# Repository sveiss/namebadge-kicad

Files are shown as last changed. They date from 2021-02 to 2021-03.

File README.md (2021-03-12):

namebadge-kicad
===============

This repo contains the Kicad data files for an animated desk toy/namebadge with the letter K, built using WS2812 LEDs (Adafruit "NeoPixels") and a Raspberry Pi Pico.

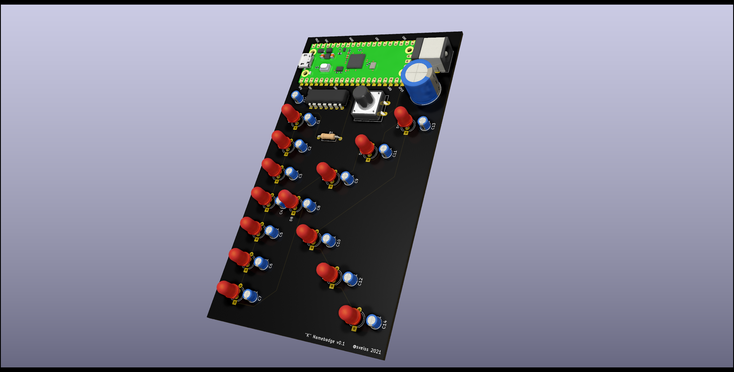
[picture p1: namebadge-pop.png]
PCB Render


*Note*: This is my first electronics project in a very long while -- don't use this project as an example of how to do things right!

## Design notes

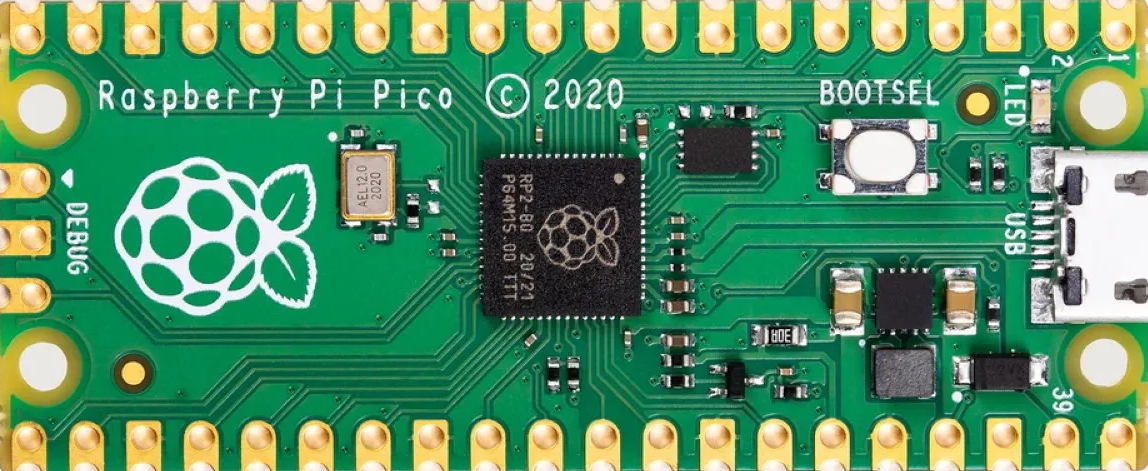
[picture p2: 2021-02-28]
raspberry-pi-pico-r3-1.snapshot.1/Raspberry Pi Pico-R3, Top View.PNG

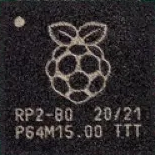
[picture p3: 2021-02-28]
raspberry-pi-pico-r3-1.snapshot.1/RP2040 Microcontroller, Raspberry Pi Pico-R3, Top View.PNG

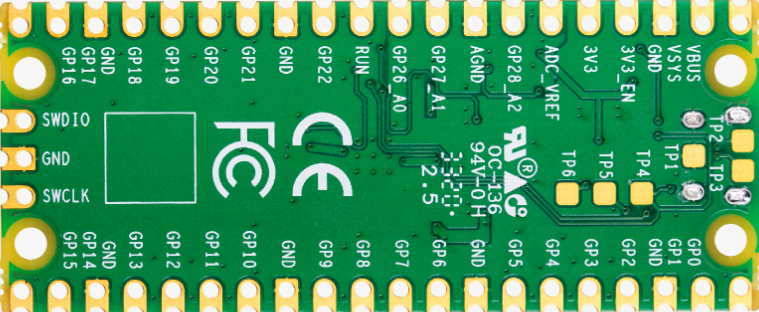
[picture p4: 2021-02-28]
raspberry-pi-pico-r3-1.snapshot.1/Raspberry Pi Pico-R3, Bottom View.PNG

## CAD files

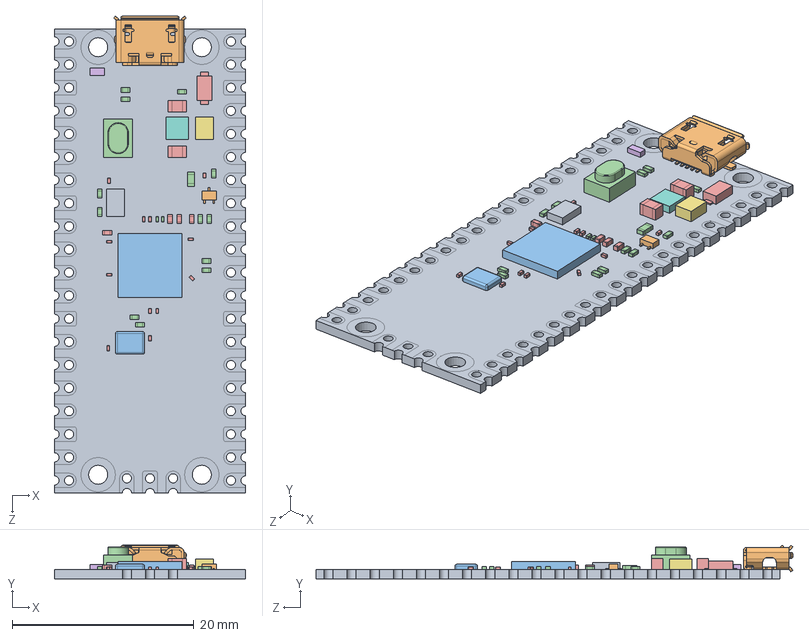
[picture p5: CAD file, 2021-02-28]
raspberry-pi-pico-r3-1.snapshot.1/Raspberry Pi Pico-R3.SLDASM
21.0 x 3.69 x 52.4 mm
PCB, Raspberry Pi Pico-R3
MicroUSB Port, Raspberry Pi Pico-R3
RP2040 Microcontroller, Raspberry Pi Pico-R3
SW1, Tact Switch, Raspberry Pi Pico-R3
D1, Diode, Schottky, Raspberry Pi Pico-R3
D2, QSME-C194, LED, Raspberry Pi Pico-R3
L1, Inductor, Raspberry Pi Pico-R3
U2, RT6150B-33GQW, Buck Boost Converter, Raspberry Pi Pico-R3
U3, W25Q16JVUXIQ, Serial NOR Flash 16 Mbit, Raspberry Pi Pico-R3
Q1, MOSFET, DMG1012T, Raspberry Pi Pico-R3
X1, X12M000000S096, 12 Mhz Crystal Resonator, Raspberry Pi Pico-R3
SMD Resistor, Configurable, Raspberry Pi Pico-R3 x 15
SMD Capacitor, Configurable, Raspberry Pi Pico-R3 x 18

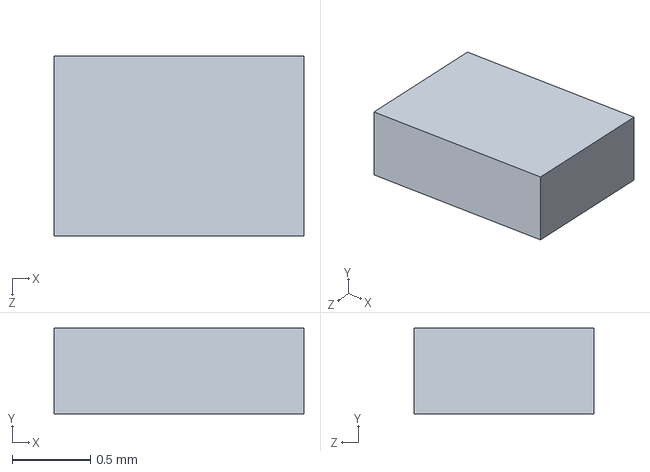
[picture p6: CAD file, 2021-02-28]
raspberry-pi-pico-r3-1.snapshot.1/D2, QSME-C194, LED, Raspberry Pi Pico-R3.SLDPRT
1.60 x 0.55 x 1.15 mm

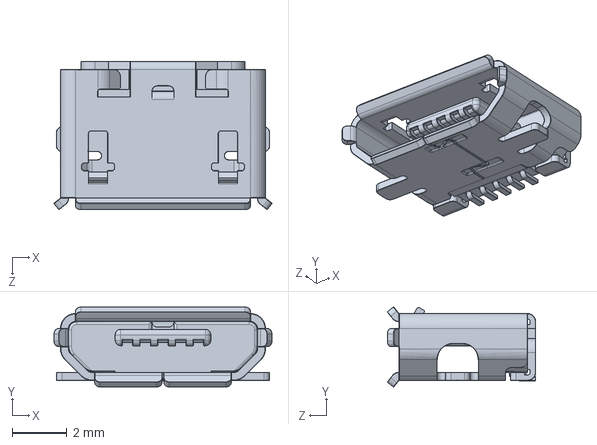
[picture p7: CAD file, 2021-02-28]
raspberry-pi-pico-r3-1.snapshot.1/MicroUSB Port, Raspberry Pi Pico-R3.SLDPRT
7.97 x 2.92 x 5.43 mm

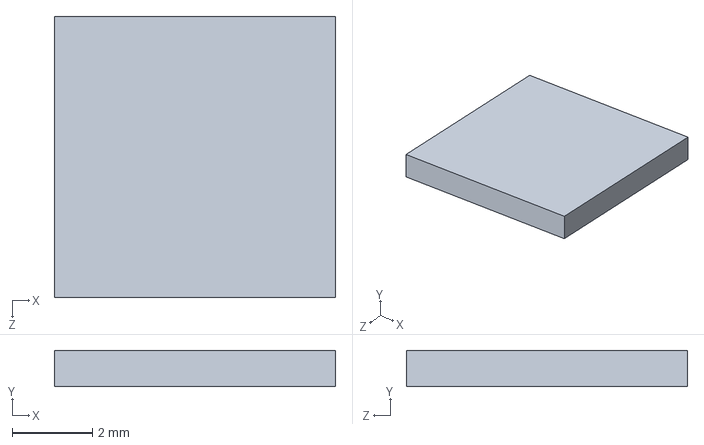
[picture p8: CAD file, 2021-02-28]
raspberry-pi-pico-r3-1.snapshot.1/RP2040 Microcontroller, Raspberry Pi Pico-R3.SLDPRT
7.00 x 0.9 x 7.00 mm

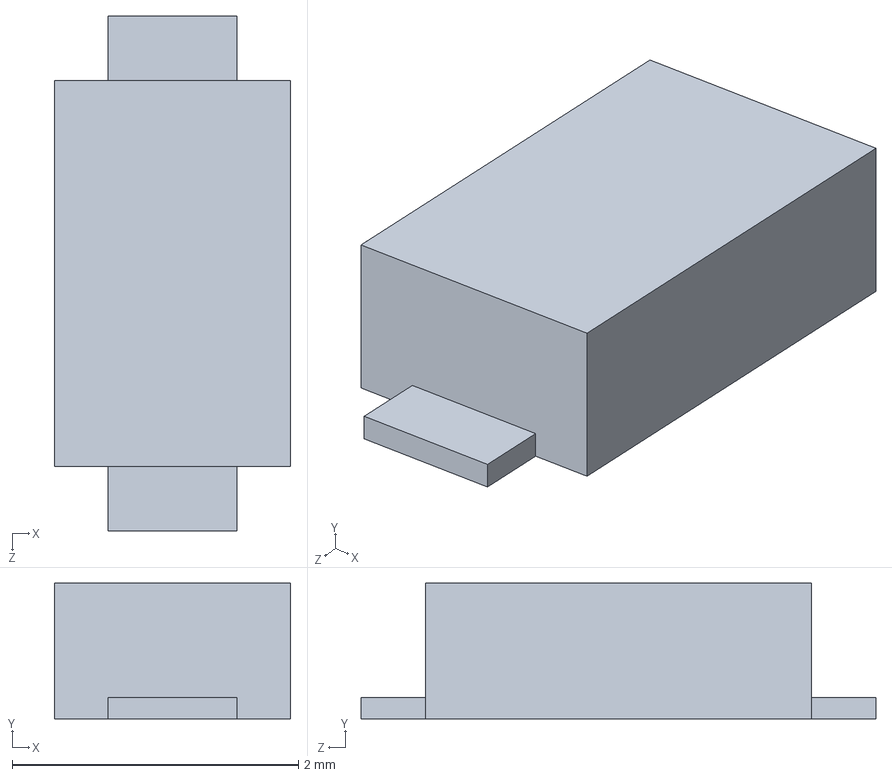
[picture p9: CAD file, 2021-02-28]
raspberry-pi-pico-r3-1.snapshot.1/D1, Diode, Schottky, Raspberry Pi Pico-R3.SLDPRT
1.65 x 0.95 x 3.60 mm

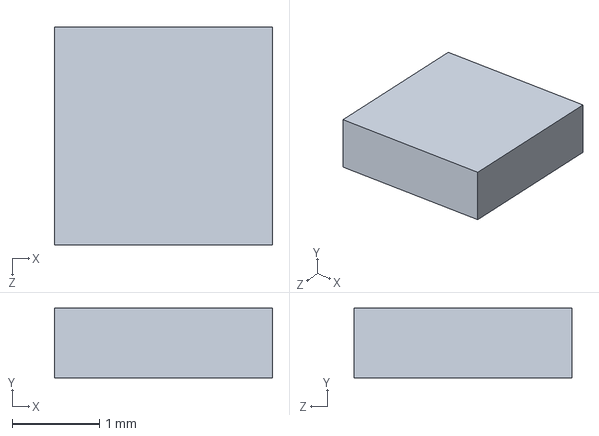
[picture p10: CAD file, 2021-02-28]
raspberry-pi-pico-r3-1.snapshot.1/U3, W25Q16JVUXIQ, Serial NOR Flash 16 Mbit, Raspberry Pi Pico-R3.SLDPRT
2.50 x 0.8 x 2.50 mm

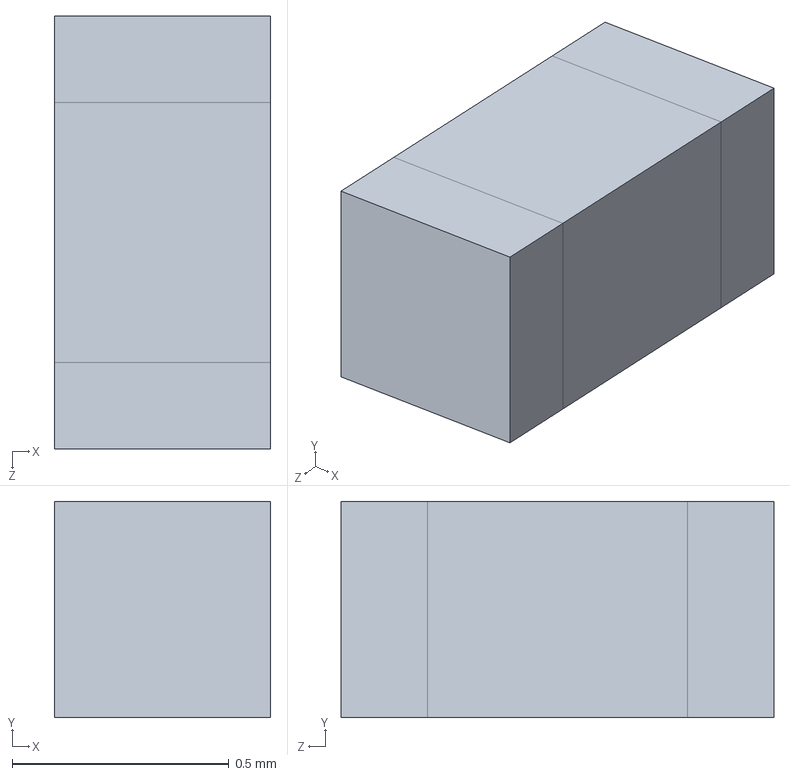
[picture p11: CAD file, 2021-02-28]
raspberry-pi-pico-r3-1.snapshot.1/SMD Capacitor, Configurable, Raspberry Pi Pico-R3.SLDPRT
0.5 x 0.5 x 1.00 mm

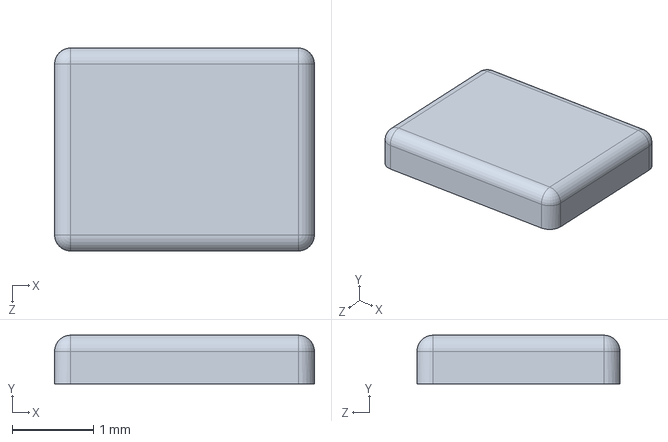
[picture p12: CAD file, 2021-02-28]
raspberry-pi-pico-r3-1.snapshot.1/X1, X12M000000S096, 12 Mhz Crystal Resonator, Raspberry Pi Pico-R3.SLDPRT
3.20 x 0.6 x 2.50 mm

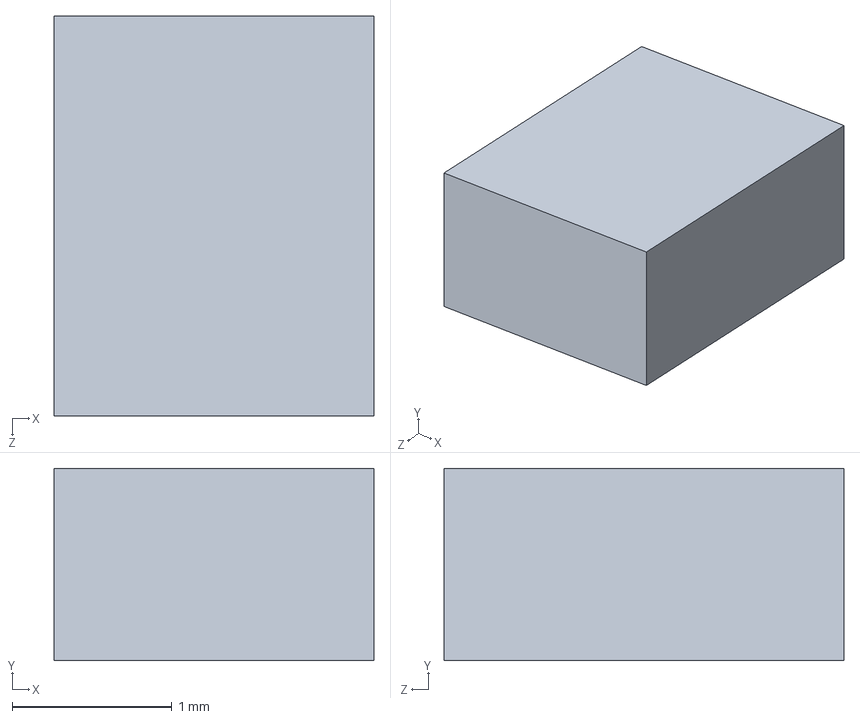
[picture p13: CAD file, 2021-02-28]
raspberry-pi-pico-r3-1.snapshot.1/L1, Inductor, Raspberry Pi Pico-R3.SLDPRT
2.00 x 1.20 x 2.50 mm

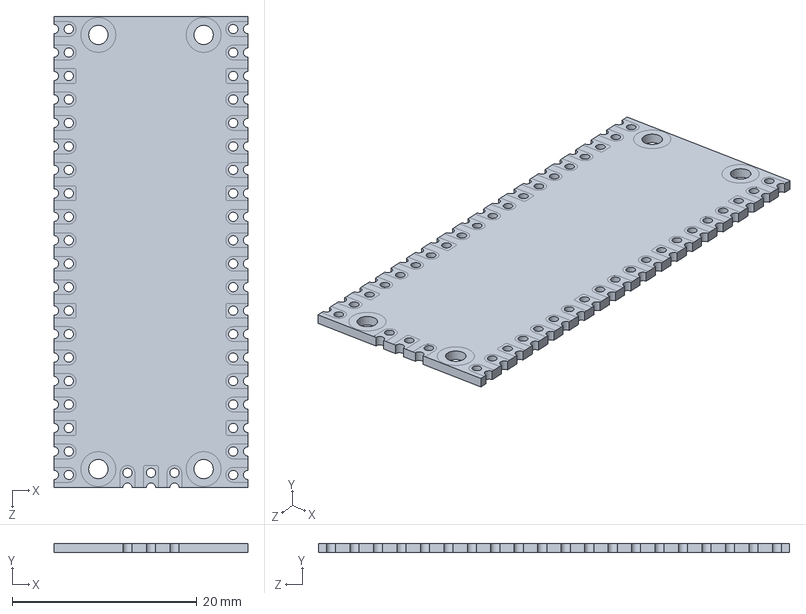
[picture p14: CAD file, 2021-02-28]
raspberry-pi-pico-r3-1.snapshot.1/PCB, Raspberry Pi Pico-R3.SLDPRT
21.0 x 1.00 x 51.0 mm

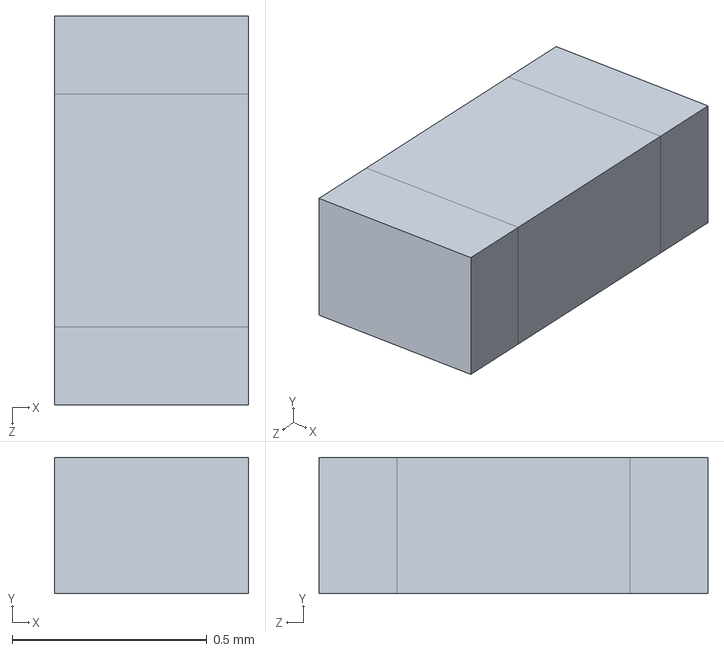
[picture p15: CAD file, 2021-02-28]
raspberry-pi-pico-r3-1.snapshot.1/SMD Resistor, Configurable, Raspberry Pi Pico-R3.SLDPRT
0.5 x 0.35 x 1.00 mm

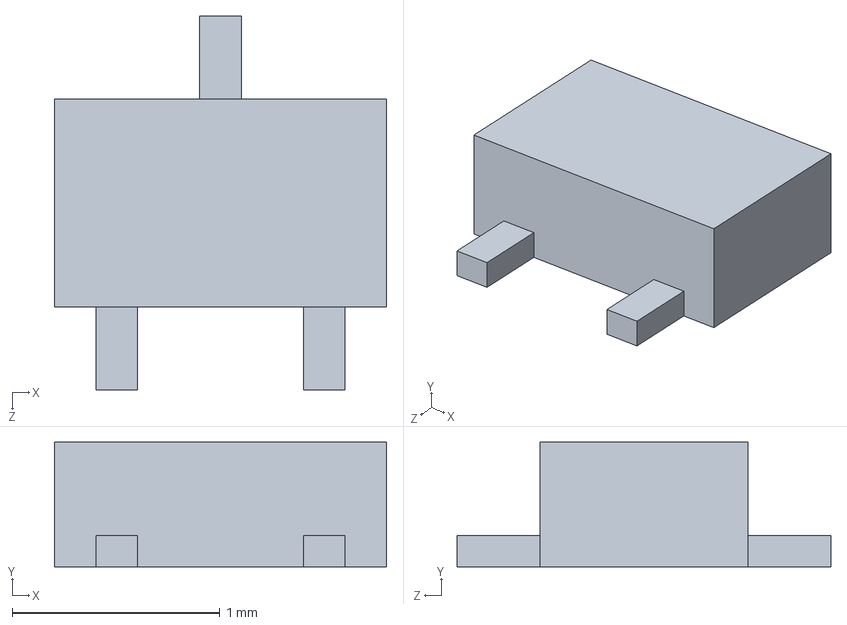
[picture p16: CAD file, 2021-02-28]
raspberry-pi-pico-r3-1.snapshot.1/Q1, MOSFET, DMG1012T, Raspberry Pi Pico-R3.SLDPRT
1.60 x 0.6 x 1.80 mm

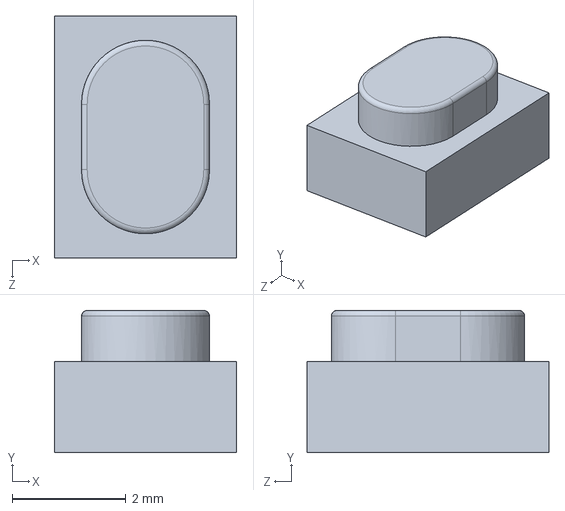
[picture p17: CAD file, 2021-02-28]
raspberry-pi-pico-r3-1.snapshot.1/SW1, Tact Switch, Raspberry Pi Pico-R3.SLDPRT
3.20 x 2.50 x 4.25 mm

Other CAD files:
raspberry-pi-pico-r3-1.snapshot.1/U2, RT6150B-33GQW, Buck Boost Converter, Raspberry Pi Pico-R3.SLDPRT
raspberry-pi-pico-r3-1.snapshot.1/Raspberry Pi Pico-R3.x_b

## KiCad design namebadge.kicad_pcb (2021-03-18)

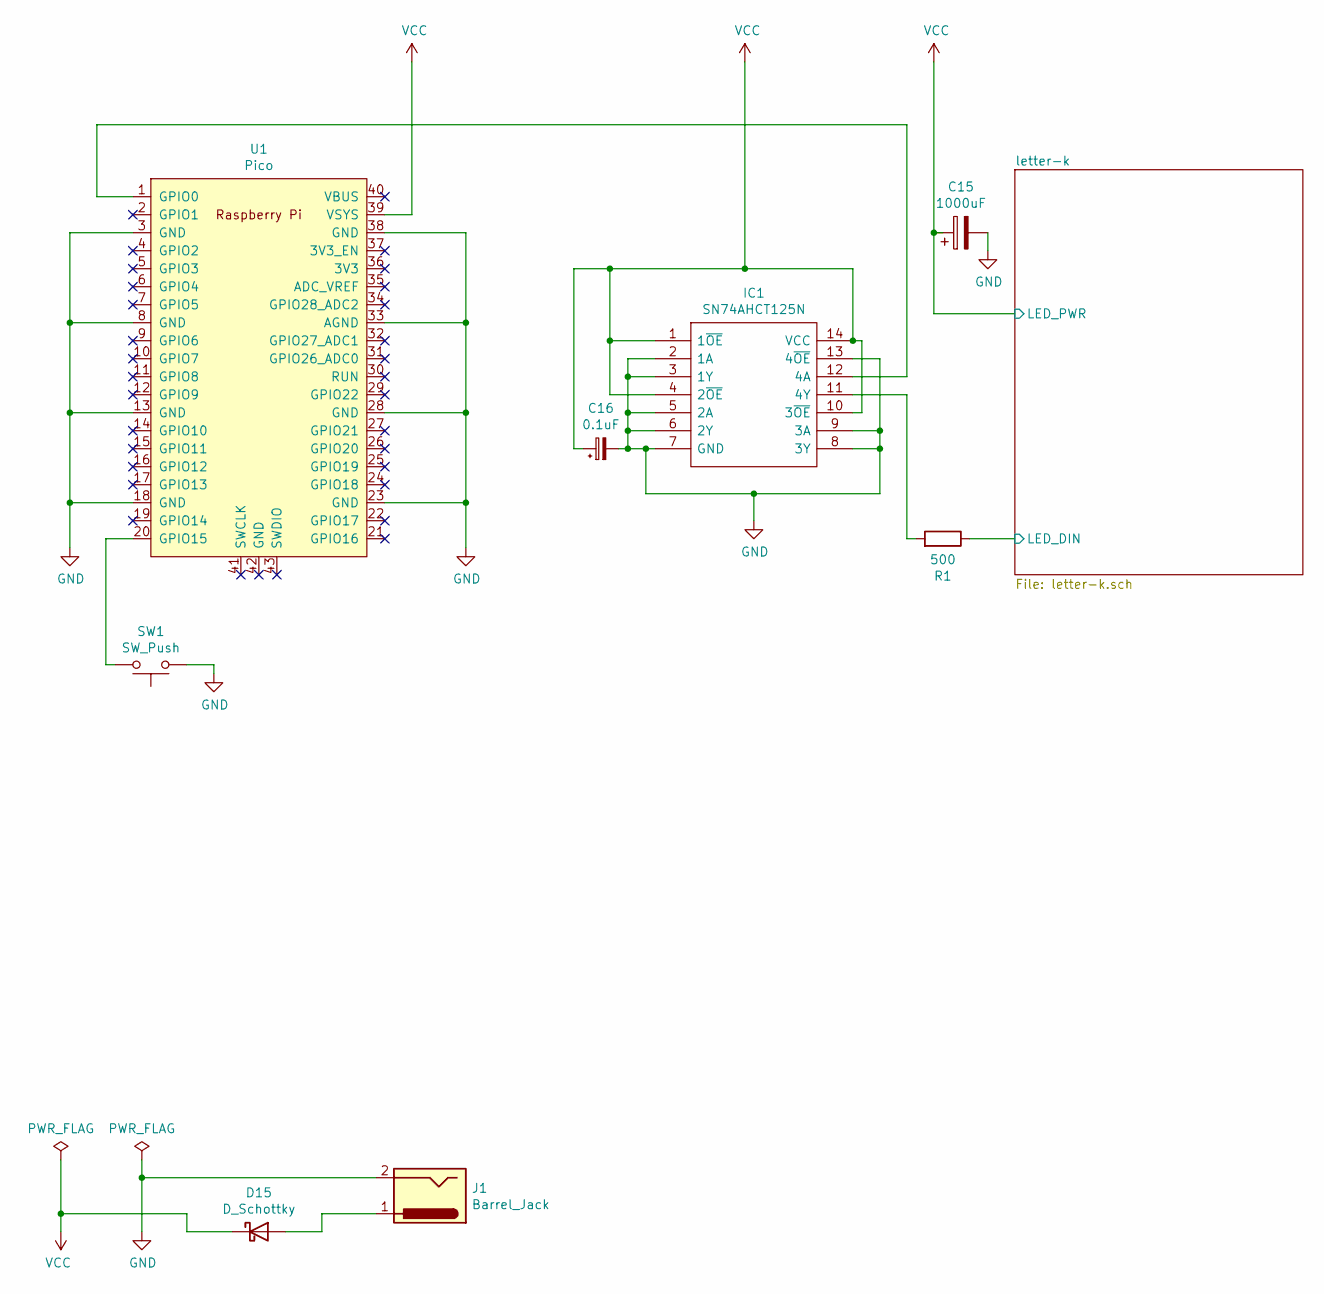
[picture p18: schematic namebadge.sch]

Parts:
C15: 1000uF; CP_Radial_D12.5mm_P5.00mm
C16: 0.1uF; C_Disc_D4.7mm_W2.5mm_P5.00mm
D15: D_Schottky; D_DO-41_SOD81_P10.16mm_Horizontal
IC1: SN74AHCT125N; DIP-14_W7.62mm; Manufacturer_Part_Number SN74AHCT125N; Mouser Part Number 595-SN74AHCT125N
J1: Barrel_Jack; BarrelJack_CUI_PJ-063AH_Horizontal
R1: 500; R_Axial_DIN0207_L6.3mm_D2.5mm_P10.16mm_Horizontal
SW1: SW_Push; SW_PUSH-12mm
U1: Pico; RPi_Pico_SMD_TH

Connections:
/letter-k/LED_DIN: R1.1; also elsewhere on the board
GND: C15.2, C16.2, IC1.2 (1A), IC1.3 (1Y), IC1.5 (2A), IC1.6 (2Y), IC1.7 (GND), IC1.8 (3Y), IC1.9 (3A), IC1.13 (4~OE), J1.2, SW1.1, U1.3 (GND), U1.8 (GND), U1.13 (GND), U1.18 (GND), U1.23 (GND), U1.28 (GND), U1.33 (AGND), U1.38 (GND); also elsewhere on the board
unnamed: D15.2 (A), J1.1
unnamed: IC1.11 (4Y), R1.2
unnamed: IC1.12 (4A), U1.1 (GPIO0)
unnamed: SW1.2, U1.20 (GPIO15)
VCC: C15.1, C16.1, D15.1 (K), IC1.1 (1~OE), IC1.4 (2~OE), IC1.10 (3~OE), IC1.14 (VCC), U1.39 (VSYS); also elsewhere on the board

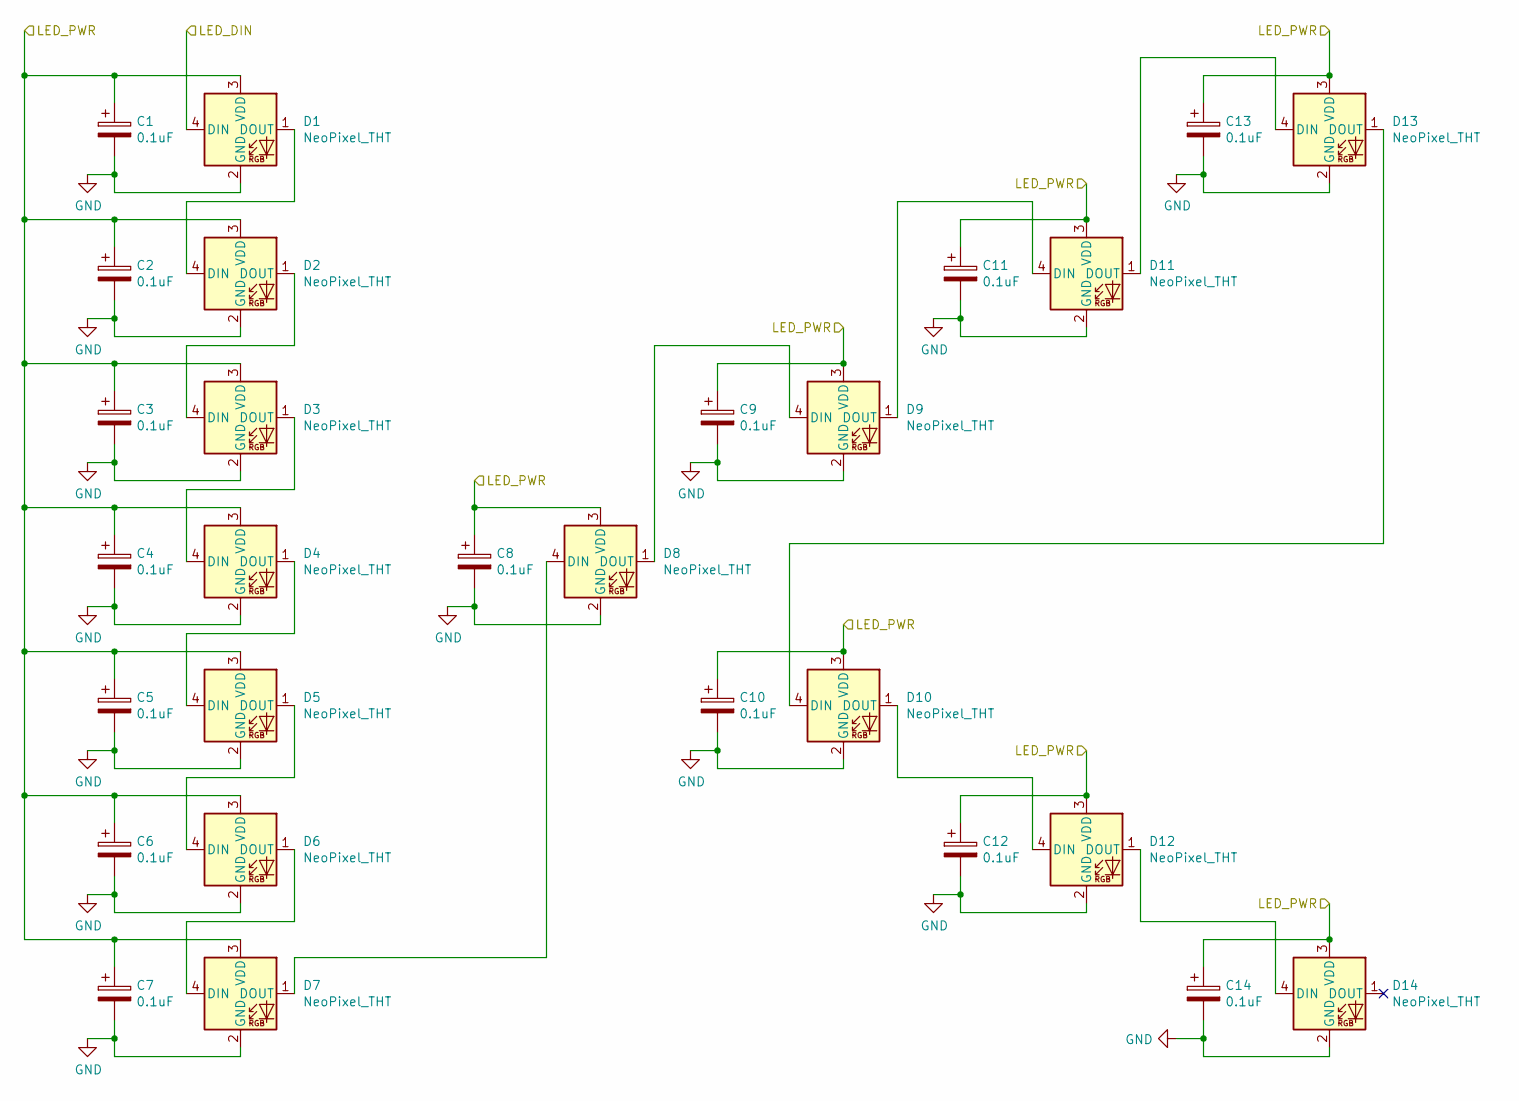
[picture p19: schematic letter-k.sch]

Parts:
C1, C2, C3, C4, C5, C6, C7, C8, C9, C10, C11, C12, C13, C14: 0.1uF; C_Disc_D4.7mm_W2.5mm_P5.00mm
D1, D2, D3, D4, D5, D6, D7, D8, D9, D10, D11, D12, D13, D14: NeoPixel_THT; LED_D5.0mm-4_RGB_Wide_Pins

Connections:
/letter-k/LED_DIN: D1.4 (DIN); also elsewhere on the board
GND: C1.2, C2.2, C3.2, C4.2, C5.2, C6.2, C7.2, C8.2, C9.2, C10.2, C11.2, C12.2, C13.2, C14.2, D1.2 (GND), D2.2 (GND), D3.2 (GND), D4.2 (GND), D5.2 (GND), D6.2 (GND), D7.2 (GND), D8.2 (GND), D9.2 (GND), D10.2 (GND), D11.2 (GND), D12.2 (GND), D13.2 (GND), D14.2 (GND); also elsewhere on the board
unnamed: D1.1 (DOUT), D2.4 (DIN)
unnamed: D2.1 (DOUT), D3.4 (DIN)
unnamed: D3.1 (DOUT), D4.4 (DIN)
unnamed: D4.1 (DOUT), D5.4 (DIN)
unnamed: D5.1 (DOUT), D6.4 (DIN)
unnamed: D6.1 (DOUT), D7.4 (DIN)
unnamed: D7.1 (DOUT), D8.4 (DIN)
unnamed: D8.1 (DOUT), D9.4 (DIN)
unnamed: D10.1 (DOUT), D12.4 (DIN)
unnamed: D10.4 (DIN), D13.1 (DOUT)
unnamed: D11.1 (DOUT), D13.4 (DIN)
unnamed: D9.1 (DOUT), D11.4 (DIN)
unnamed: D12.1 (DOUT), D14.4 (DIN)
VCC: C1.1, C2.1, C3.1, C4.1, C5.1, C6.1, C7.1, C8.1, C9.1, C10.1, C11.1, C12.1, C13.1, C14.1, D1.3 (VDD), D2.3 (VDD), D3.3 (VDD), D4.3 (VDD), D5.3 (VDD), D6.3 (VDD), D7.3 (VDD), D8.3 (VDD), D9.3 (VDD), D10.3 (VDD), D11.3 (VDD), D12.3 (VDD), D13.3 (VDD), D14.3 (VDD); also elsewhere on the board

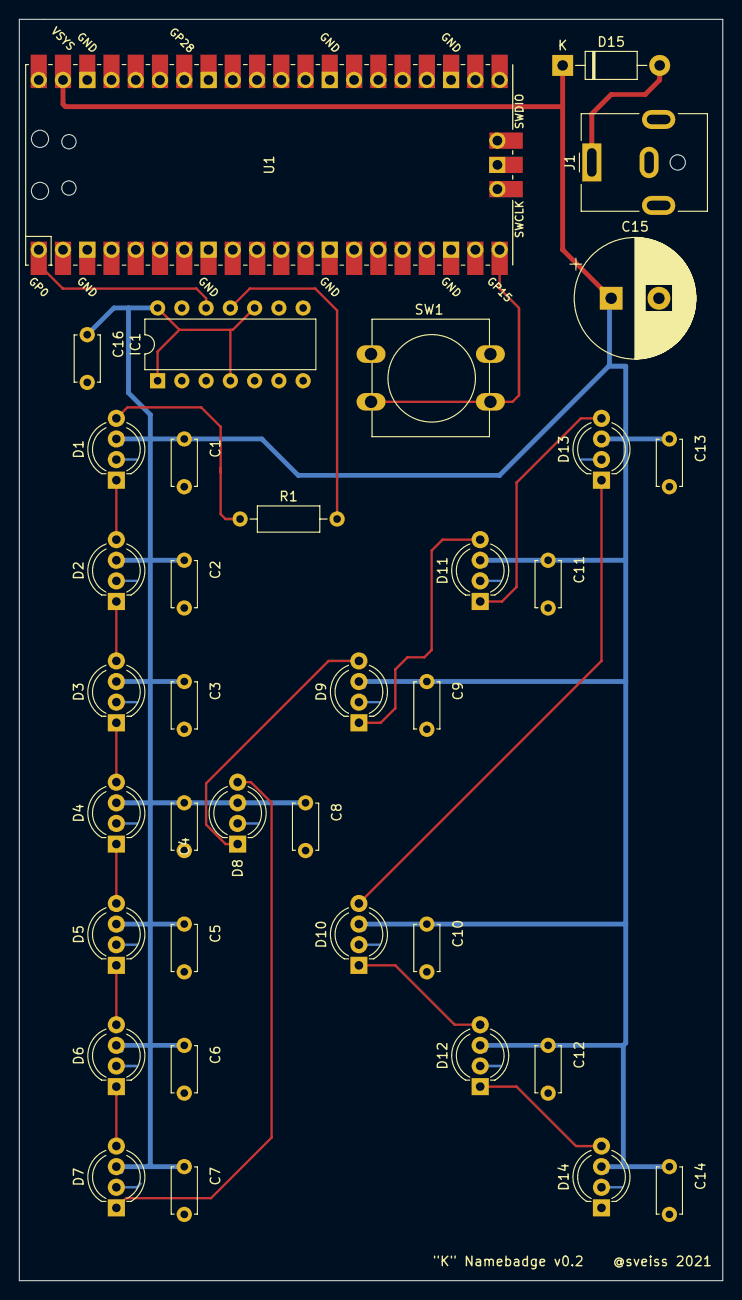
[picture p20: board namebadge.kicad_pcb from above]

Board: 2 copper layers, 73.7 x 132.1 mm, 36 parts (0 on the bottom side), 20 nets.

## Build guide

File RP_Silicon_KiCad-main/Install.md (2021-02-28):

# Install KiCad libraries

## Manage Symbol Libraries

Accessed from the Preferences menu, add a new line with the +, give it a name and use the folder icon to point to the directory/folder where you have KiCadLibraries.

Manage Symbol Libraries screen shot


## Manage Footprint Libraries

Ditto! Accessed from the Preferences menu, add a new line with the +, give it a name and use the folder icon to point to the directory/folder where you have KiCadLibraries.

Manage Footprint Libraries screen shot


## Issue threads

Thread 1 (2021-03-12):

/OE on level shifter not connected

sveiss, 2021-03-12:
/OE on the level shifter is not connected, which means it likely won't work at all.

This will need a bodge wire to GND on the first batch of PCBs.

sveiss, 2021-03-18:
Actually, not needed; I can't read a datasheet. We did ground the /OE for unit 4, which is the only one we're using.

It's a non-inverting shifter, so we could get away with grounding all the unused pins.

Closed 2021-03-12.

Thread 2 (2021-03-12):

Not enough clearance for USB port on Pico when surface mounted

sveiss, 2021-03-12:
If the Pico is surface mounted to the PCB using the castellations, as was my original intention, there isn't enough clearance to connect a Micro USB plug.

We can fix this by moving it to the edge of the board, so the port overhangs the edge of the PCB (like it does on the Pico itself).

For the first PCB run, we can either:

 - [ ] mount the Pico on 0.1" headers, so it's raised up from the PCB
 - [ ] forego the USB port entirely, solder headers to the SWD pins for programming, and power the board from the DC jack
 - [ ] simply find a super-slim Micro USB cable!

Closed 2021-03-18.

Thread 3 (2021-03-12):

Decoupling caps shouldn't be polarized

sveiss, 2021-03-12:
I'm using the polarized symbol for the decoupling caps on the NeoPixels, and a PCB footprint appropriate for a smallish electrolytic.

The caps I've ordered are small unpolarized ceramics, so the schematic and footprint should be updated. (and I think unpolarized are more appropriate for decoupling anyway?)

sveiss, 2021-03-18:
The ordered caps arrived, and the lead shape is wrong for the footprint anyway. (They'll fit, with some bending).

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

A more appropriate footprint will fix this too.

Closed 2021-03-18.

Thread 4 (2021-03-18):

Power inputs not safe

sveiss, 2021-03-18:
The current design connects the power jack to VBUS. This configuration isn't safe: if a USB power supply is connected, the two +5v lines will be connected together. On the v0.1 boards, we should either leave the jack off, or seal the USB jack with hot glue to avoid accidental fireworks. (Since the USB socket doesn't work when soldered castellated, sealing the USB is probably best...)

The [datasheet ](https://datasheets.raspberrypi.org/pico/pico-datasheet.pdf)suggests a couple of alternatives: we can use a Schottky diode to feed our external power into VSYS, and whichever has the higher voltage will be used. We can also draw out of VSYS, which is downstream of an on-board Schottky with a 1A rating. Our LEDs are rated at 60mA max, 60*14 = 840mA, which gives us just enough headroom to power the Pico as well.

That should let us power from a 1A 5v wallwart, or from a 1A USB charger without issue.

Closed 2021-03-18.

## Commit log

2021-02-28 power cap
    [letter-k.sch, namebadge.kicad_pcb, namebadge.sch]
2021-02-28 level shifter
    [namebadge.kicad_pcb, namebadge.sch]
2021-02-28 DC jack take 1
    [namebadge.kicad_pcb, namebadge.sch]
2021-02-28 flip the pico
    [namebadge.kicad_pcb]
2021-02-28 fix traces after flip
    [namebadge.sch]
2021-02-28 decoup for level shifter, layout cleanup
    [namebadge.kicad_pcb, namebadge.sch]
2021-02-28 fix dropped connection to gpio
    [namebadge.kicad_pcb, namebadge.sch]
2021-02-28 print setup
    [namebadge.kicad_pcb]
2021-02-28 3d model bits
    [D1, Diode, Schottky, Raspberry Pi Pico-R3.SLDPRT, D2, QSME-C194, LED, Raspberry Pi Pico-R3.SLDPRT, L1, Inductor, Raspberry Pi Pico-R3.SLDPRT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]
2021-03-12 remove rendered gerbers
    [namebadge-B_Cu.gbr, namebadge-B_Mask.gbr, namebadge-B_SilkS.gbr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]
2021-03-12 Ground /OE on level shifter.
    Fixes #1.
    [namebadge.kicad_pcb, namebadge.sch]
2021-03-12 normalize endings
    [letter-k.sch, namebadge.kicad_pcb, namebadge.sch]
2021-03-18 Fix capacitor footprints and Pico location.
    Fixes #2, #3.
    [namebadge.kicad_pcb]
2021-03-18 Connect rest of pins on the buffer to VCC/Gnd. Resize copper plane to cover more of the Pico after its move. Fix a couple of unconnected tracks. PCB version on silkscreen to v0.2.
    Also updates schematic with capacitor footprint changes.
    [letter-k.sch, namebadge.kicad_pcb, namebadge.sch]
2021-03-18 Adds a Schottky on the DC input and moves it to VSYS, not VBUS.
    Fixes #4.
    [namebadge.kicad_pcb, namebadge.sch]
2021-03-18 Fix silkscreen for Pico
    [namebadge.kicad_pcb]
